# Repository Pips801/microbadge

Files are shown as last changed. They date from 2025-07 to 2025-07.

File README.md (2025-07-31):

# Microbadge
Do you find Minibadges too big? Do you want to go even smaller? Try out the Microbadge! A minibadge can hold 6 of them!

The Microbadge is a 6mm x 6mm badge that uses 1.00mm pin headers to connect to a carrier board.
# Version 2! Do not use V1 anymore!
The Microbadge has been updated to V2 to support I2C, 1.00mm pins, and an additional 2x PROG pins for programming.  The microbadge has shrunk from 6.9mm to 6mm, and is small enough that you can fit 6 on a minibadge.



# Pictures
Full MicrobadgeSimple Microbadge

Full MicrobadgeSimple Microbadge

There are two Microbadge types - Simple and Full. Simple exposes +VBATT, CLK, 3x GND, and 2x +3v. The Full Microbadge adds two programming pins, and I2C SDA and SCL.

Full Microbadge footprint

 # Importing into Kicad
 1. From the **Project Viewer**, **Symbol Editor** or the **Schematic Editor**, select **Preferences** > **Manage Symbol Libraries...** 



 2. Under **Global Libraries**, click **Add Existing Library to Table**, Select the `Microbadge V2.kicad-sym` file. I personally put it in `Documents\KiCad\{version}\symbols` on Windows, there's an equivalent folder on Mac and Linux as well.
 3. From the **Project Viewer**, **Footprint Editor**, or **PCB Editor**, select **Preferences** > **Manage Footprint Libraries...** 



 4. Under **Global Libraries**, click **Add Existing**, Select the `Microbadge V2.pretty` folder. I personally put it in `Documents\KiCad\{version}\footprints` on Windows, there's an equivalent folder on Mac and Linux as well.

# Creating a Microbadge carrier board (Minibadge)
This assumes you already have the SAINTCON Minibadge footprints and symbols added to your libraries.
 1. Open the **Schematic Editor**, and import a Minibadge symbol and at least one Microbadge symbol.
 2. Atatch **Power Symbols** and **Global Labels** to the Minibadge symbol. If you want blinking, don't forget to connect CLK. 



 3. Atatch the same Symbols to each Microbadge symbol you created. Each symbol will be a microbadge socket. 



 4. Select **Assign Footprints** > Assign a **Minibadge Footprint** (`Minibadge_Simple`, `Minibadge_Full`) to the **Minibadge** (not a slot), and assign a **Microbadge socket** footprint to the **Microbadges**. 



 5. Do your schematic and PCB work. Add LEDs, resistors, and other components.

# Creating a Microbadge
 1. Open the Schematic editor, and import a Microbadge symbol.
 2. Atatch **Power Symbols** and **Global Labels** to the microbadge. If you want blinking, don't forget to connect **CLK**. 



 3. Wire up your LEDs, resistors, and other components you want to use.
 4. Select **Assign Footprints** > Assign a Microbadge footprint (Square or Round, **not** a Socket!) to the **Microbadge**
 5. Assign `0603` or `0201` sized components to your LEDs and resistors. You have very little space to work with, so the smaller, the better.
 6. Do your PCB routing, silkscreening, etc.

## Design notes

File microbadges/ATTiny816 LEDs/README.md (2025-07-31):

# ATTiny816 LED Microbadge
## Pictures





## Description
A fully-programmable RGB LED Microbadge.
Features:
 * Microbadge with MCU and LEDs
 * 4x WS2812B-1010 RGB LEDs controlled by the NeoPixel library
 * ATTiny 816 MCU (8KB flash) programmable via UPDI through the ArduinoIDE
 * Diode to prevent reverse-voltage issues

## Programming
 * Supply 5v, GND, and UPDI. UPDI programming port is the normally NC port next to the CLK pin. It has an arrow pointing to the pin on either side of the board.

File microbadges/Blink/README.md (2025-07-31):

# BLINK Microbadge
## Pictures



## Description
A microbadge that uses the CLK pin to Blink

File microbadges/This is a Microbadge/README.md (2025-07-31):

# This is MICROBADGE
## Pictures



## Description
A Microbadge, showing you what a Microbadge is.

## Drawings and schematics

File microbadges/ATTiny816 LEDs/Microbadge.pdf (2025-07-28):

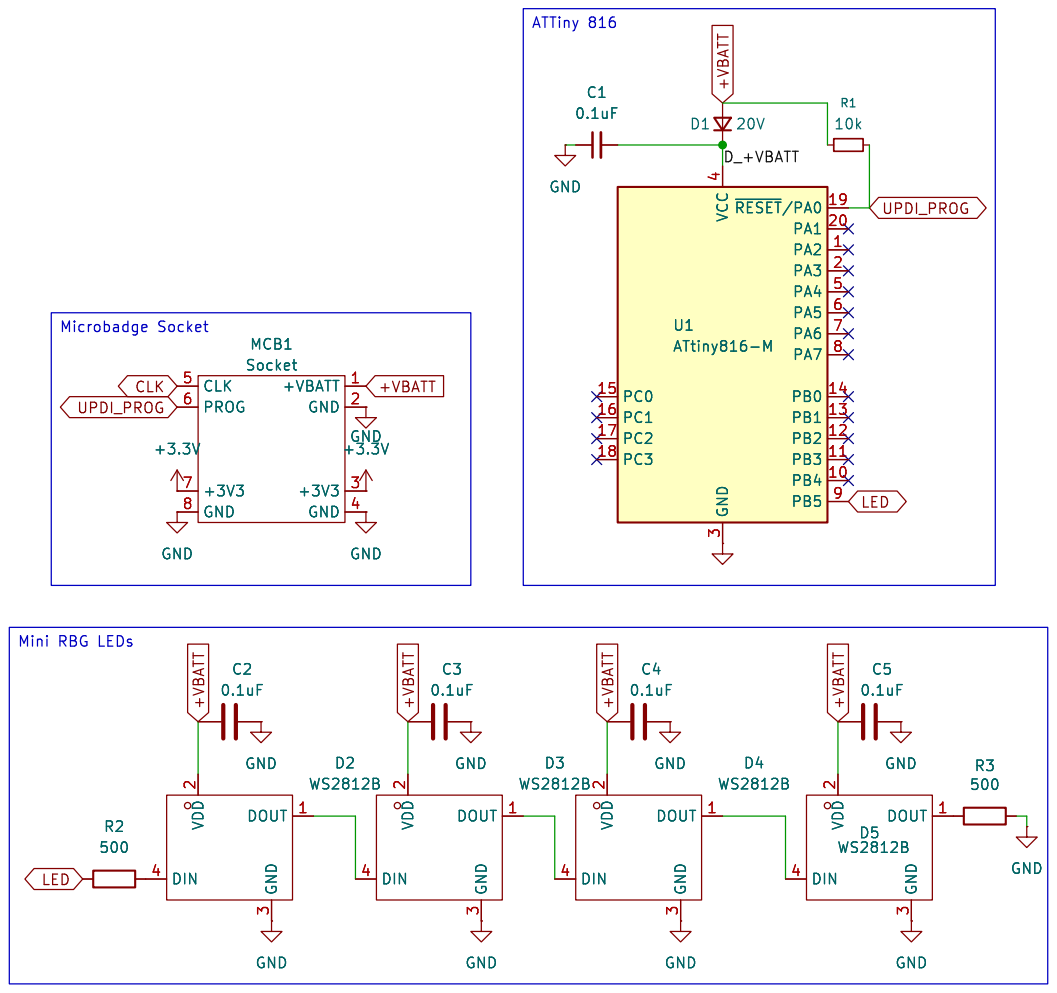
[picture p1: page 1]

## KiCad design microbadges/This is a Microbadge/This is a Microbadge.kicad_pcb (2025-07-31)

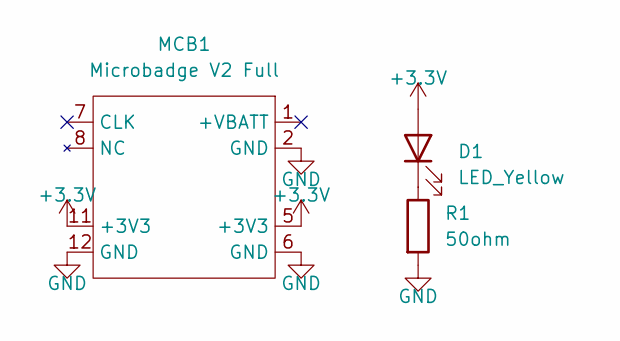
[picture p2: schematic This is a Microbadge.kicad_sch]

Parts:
D1: LED_Yellow; LED_0603_1608Metric; LCSC Part # C89811
MCB1: Microbadge V2 Full; Microbadge_V2_simple_round
R1: 50ohm; R_0402_1005Metric; LCSC Part # C25120

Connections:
+3.3V: D1.2 (A), MCB1.5 (+3V3), MCB1.11 (+3V3)
GND: MCB1.2 (GND), MCB1.6 (GND), MCB1.12 (GND), R1.2
unnamed: D1.1 (K), R1.1

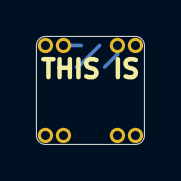
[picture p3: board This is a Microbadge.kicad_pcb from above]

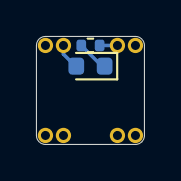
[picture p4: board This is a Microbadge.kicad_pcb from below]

Board: 2 copper layers, 6.0 x 6.0 mm, 3 parts (2 on the bottom side), 3 nets.

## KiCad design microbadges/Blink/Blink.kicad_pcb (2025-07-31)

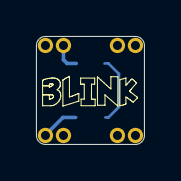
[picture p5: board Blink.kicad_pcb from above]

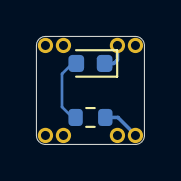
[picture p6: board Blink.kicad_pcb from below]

Board: 2 copper layers, 6.0 x 6.0 mm, 3 parts (2 on the bottom side), 3 nets.

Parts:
D1: LED; LED_0603_1608Metric
MCB1: Microbadge V2 Full; Microbadge_V2_simple_round
R1: R; R_0603_1608Metric

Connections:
CLK: MCB1.7 (CLK), R1.1
GND: D1.1 (K), MCB1.2 (GND), MCB1.6 (GND), MCB1.12 (GND)
unnamed: D1.2 (A), R1.2

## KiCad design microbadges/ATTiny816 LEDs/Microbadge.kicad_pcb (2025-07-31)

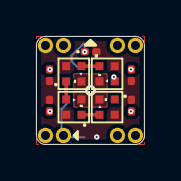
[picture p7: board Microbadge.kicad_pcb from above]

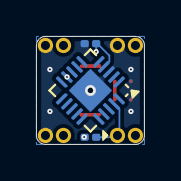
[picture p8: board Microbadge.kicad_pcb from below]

Board: 2 copper layers, 6.0 x 6.0 mm, 13 parts (3 on the bottom side), 8 nets.

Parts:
C1, C2, C3, C4, C5: 0.1uF; C_0201_0603Metric
D1: 20V; D_0201_0603Metric
D2, D3, D4, D5: WS2812B; LED-SMD_4P-L1.0-W1.0-TL_XL-1010RGBC-WS2812B
MCB1: Socket; Microbadge_V2_simple_round
R1: 10k; R_0201_0603Metric
U1: ATtiny816-M; VQFN-20-1EP_3x3mm_P0.4mm_EP1.7x1.7mm

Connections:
+VBATT: C2.1, C3.1, C4.1, C5.1, D1.2 (A), D2.2 (VDD), D3.2 (VDD), D4.2 (VDD), D5.2 (VDD), MCB1.1 (+VBATT), R1.1
/D_+VBATT: C1.2, D1.1 (K), U1.4 (VCC)
GND: C1.1, C2.2, C3.2, C4.2, C5.2, D2.3 (GND), D3.3 (GND), D4.3 (GND), D5.3 (GND), MCB1.2 (GND), MCB1.6 (GND), MCB1.12 (GND), U1.3 (GND), U1.21 (GND)
LED: D2.4 (DIN), U1.9 (PB5)
unnamed: D2.1 (DOUT), D3.4 (DIN)
unnamed: D3.1 (DOUT), D4.4 (DIN)
unnamed: D4.1 (DOUT), D5.4 (DIN)
UPDI_PROG: MCB1.8 (UPDI), R1.2, U1.19 (~RESET/PA0)

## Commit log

2025-07-25 Add ATTiny Microbadge
    [Microbadge.kicad_pcb, Microbadge.kicad_sch]
2025-07-25 Add Schematic PDF
2025-07-25 Add arrows for direction and UPDI Programming
    [Microbadge.kicad_pcb]
2025-07-28 Update ATTiny Voltage to use +VBATT instead of +3V3
    [Microbadge.kicad_pcb, Microbadge.kicad_sch]
2025-07-28 Fix label
    [Microbadge.kicad_sch]
2025-07-28 update schematic PDF
2025-07-28 Update Microbadge to V2 design
    [Microbadge.kicad_pcb, Microbadge.kicad_sch]
2025-07-28 small changes
    [Microbadge.kicad_pcb]
2025-07-28 rotate Resistor
    [Microbadge.kicad_sch]
2025-07-31 Add LCSC part numbers to components
    [Microbadge.kicad_sch]
2025-07-31 update margins for LEDs
    [Microbadge.kicad_pcb]
2025-07-31 Add Blink board
    [Blink.kicad_pcb, Blink.kicad_sch]
2025-07-31 Add this is MICROBADGE
    [This is a Microbadge.kicad_pcb, This is a Microbadge.kicad_sch]
